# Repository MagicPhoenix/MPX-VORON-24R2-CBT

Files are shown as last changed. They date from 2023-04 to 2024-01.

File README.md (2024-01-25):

# Print Guide

## Electronics_Bay

Completely skip official `electronics_bay` folder.

Print our printed parts name started with `Elec`

You totally need these:

2pcs `Elec_Din_Clip_x2.stl`

4pcs `Elec_LRS_200_Mount_x4.STL`

1pcs `Elec_M8P_Mount.STL`

## Exhaust Filter

We use nevermore in out kit, so you can completely skip official `exhaust filter` folder.

Print these parts to seal the back panel:

1pcs `Exhaust_cover.stl`

1pcs `Exhaust_filter_grill.stl`

> This mod comes from Fictio's [Exhaust_cover](Fiction/https://github.com/VoronDesign/VoronUsers/tree/master/printer_mods/Fiction/Exhaust_cover)

## Gantry

Skip these parts:

`STLs/Gantry/AB_Drive_Units/[a]_cable_cover.stl`

`STLs/Gantry/X_Axis/XY_Joints/[a]_endstop_pod_D2F_switch.stl`

`STLs/Gantry/X_Axis/XY_Joints/[a]_endstop_pod_hall_effect.stl`

`STLs/Gantry/X_Axis/XY_Joints/[a]_endstop_pod_hall_effect.stl`

`STLs/Gantry/X_Axis/XY_Joints/[a]_xy_joint_cable_bridge_2hole.stl`

`STLs/Gantry/X_Axis/XY_Joints/[a]_xy_joint_cable_bridge_3hole.stl`

`STLs/Gantry/X_Axis/X_Carriage/*`

`STLs/Gantry/X_Axis/Z_Joints/z_joint_upper_hall_effect.stl`

## Panel_Mounting

Use `deck_support_3mm_x8.stl` and skip the 4mm one.

### If you are using Disco Stick:

Skip `Z_belt_Cover` and use our `Panel_Z_Belt Cover`:

`Panel_Z_belt_cover_A.stl`

`Panel_Z_belt_cover_B.stl`

`Panel_Z_belt_cover_Route_A.stl`

`Panel_Z_belt_cover_Route_B.stl`

> The route Z Belt Cover comes from tanaes's [whopping_Voron_mods](https://github.com/tanaes/whopping_Voron_mods/tree/main/Z_belt_cable_cover/STL)

## Skirts

Use `power_inlet_IECGS_1.2mm.stl` and skip other `power_inlet_*`

## Z Endstop

Skip this folder, we use VORON Tap as z endstop. 

## VORON Tap

Print these parts and follow offical tap guide.

https://github.com/VoronDesign/Voron-Tap/tree/main/STLs

Print `Tap_Upper_PCB_r2.stl` and skip other `Tap_Upper_*`

## Stealthburner

Skip `X_Carriage` folder

Skip `Clockwork2/cable_door.stl` and print `cable_door_for_pcb.stl`

Skip `Clockwork2/chain_*`

Print these from our github:

Print `Toolhead_Cable_Bridge.STL`

Print `Toolhead_Can_Cable_Fix.stl`

## Disco Strick 

Print 2pcs `LED_2020_x2.stl`

> This mod comes from [Daylight](https://github.com/VoronDesign/Voron-Hardware/tree/master/Daylight/Disco_on_a_stick_XXL)

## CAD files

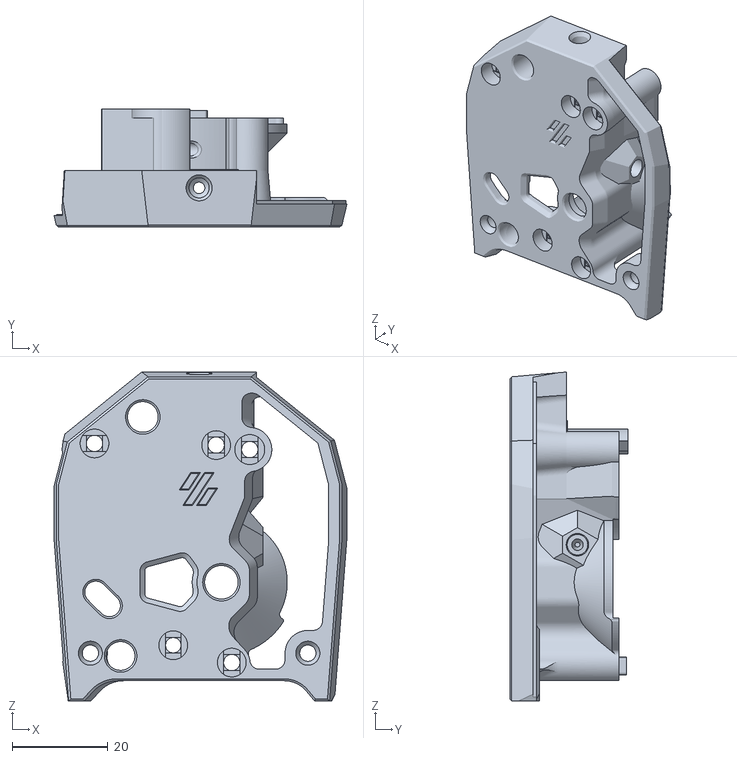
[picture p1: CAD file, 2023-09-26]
Printed Parts/Toolhead_cw2_main_body_ebbsb.stl
61.2 x 24.7 x 68.7

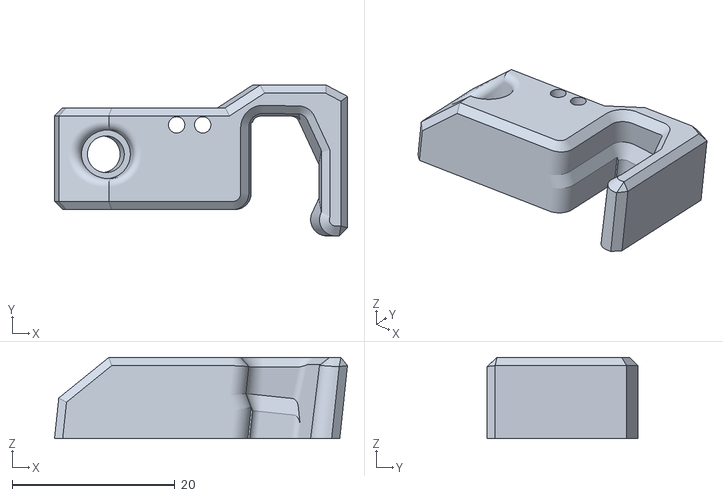
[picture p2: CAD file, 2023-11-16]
Printed Parts/Toolhead_Can_Cable_Fix.stl
36.0 x 18.5 x 9.95

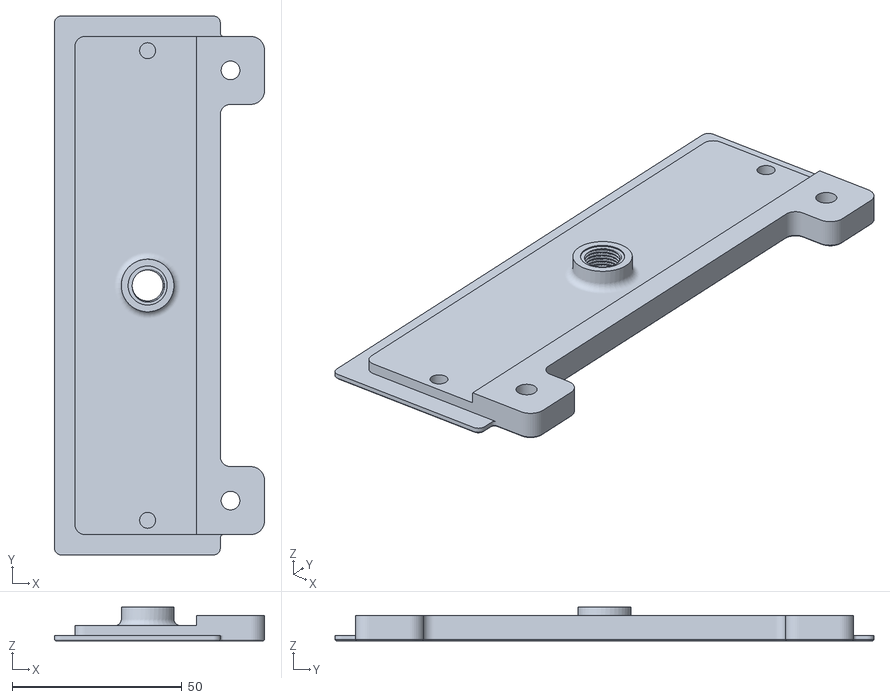
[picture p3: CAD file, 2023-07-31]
Printed Parts/Exhaust_cover.stl
61.8 x 158.6 x 10.00

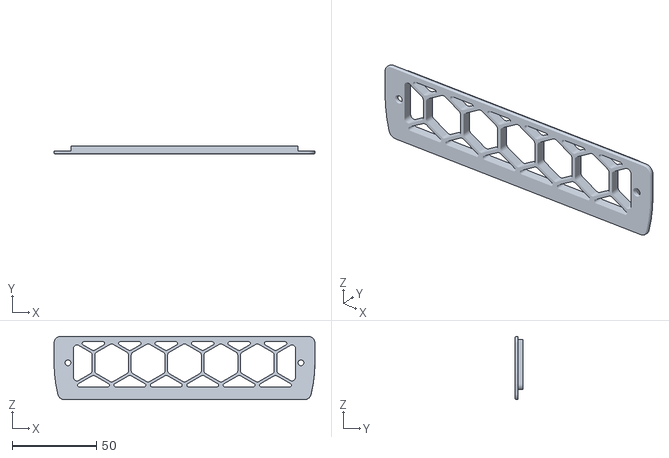
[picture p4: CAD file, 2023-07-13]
Printed Parts/Exhaust_grill.stl
154.8 x 4.60 x 37.6

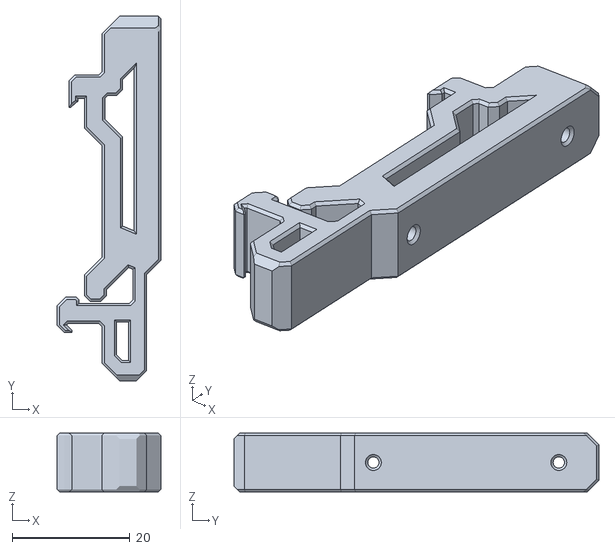
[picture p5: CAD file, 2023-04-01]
Printed Parts/Elec_Din_Clip_x2.stl
17.6 x 62.0 x 10.0

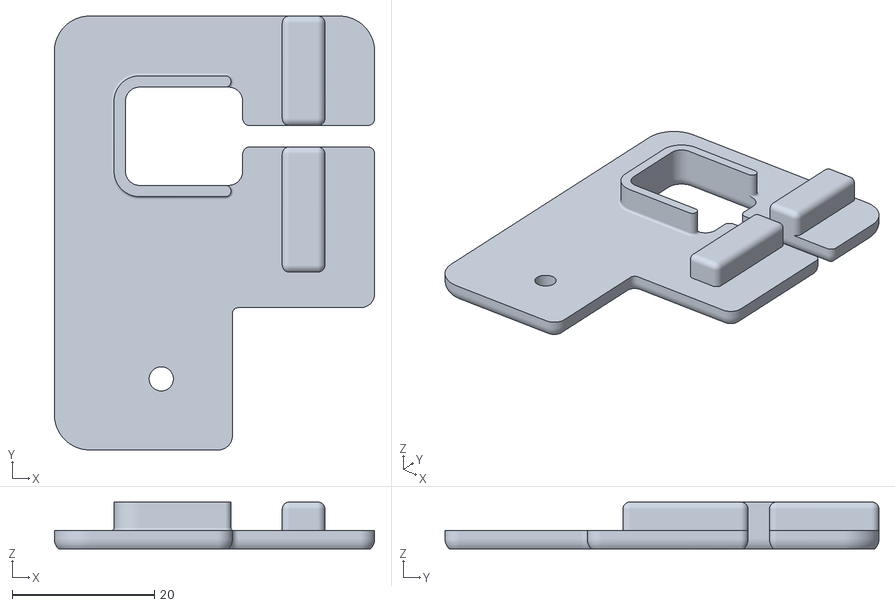
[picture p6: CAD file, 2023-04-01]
Printed Parts/Panel_Z_belt_cover_A.stl
45.0 x 61.0 x 6.60

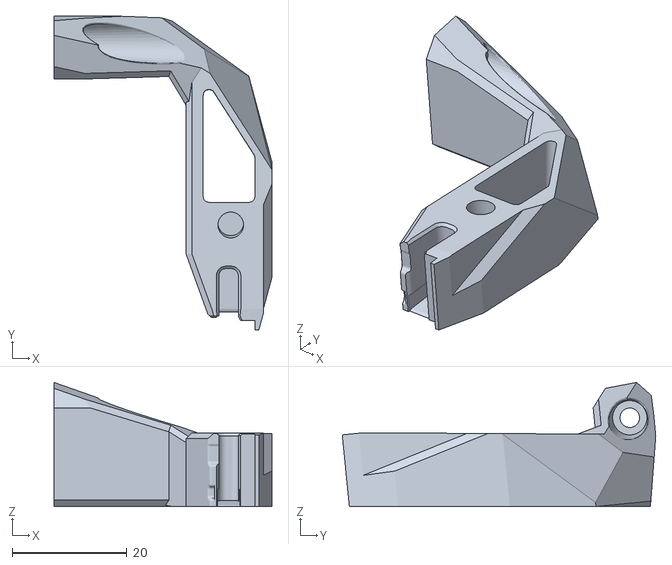
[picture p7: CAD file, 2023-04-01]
Printed Parts/Toolhead_Cable_Bridge.STL
38.0 x 54.7 x 21.7

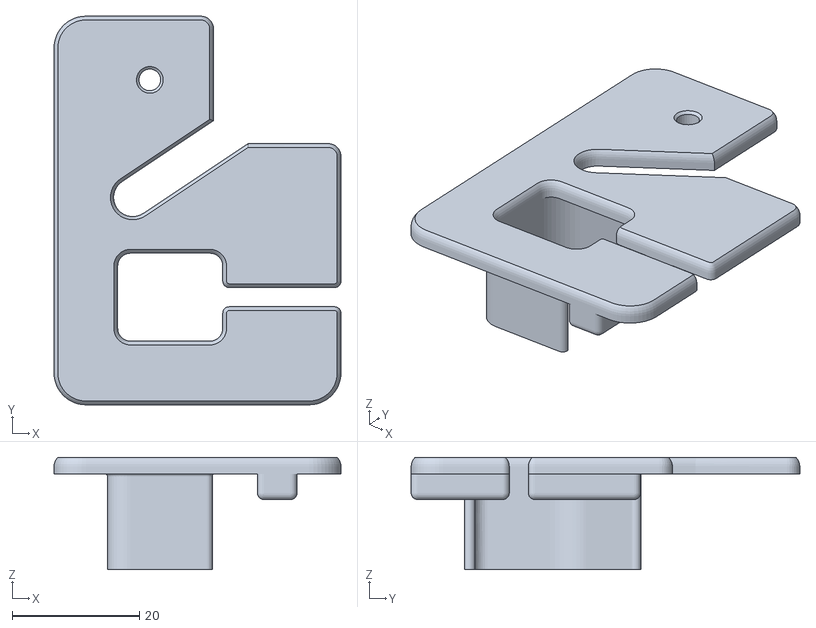
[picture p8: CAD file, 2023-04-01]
Printed Parts/Panel_Z_belt_cover_Route_A.stl
45.0 x 61.0 x 17.6

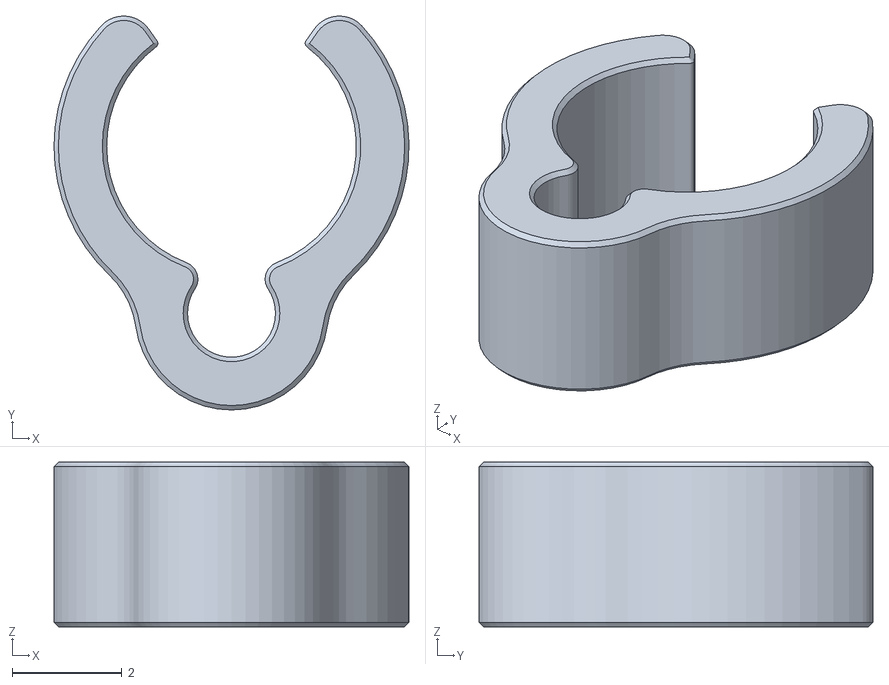
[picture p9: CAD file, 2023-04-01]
Printed Parts/Toolhead_[Optinal]Cable_Clip.STL
6.46 x 7.17 x 3.00

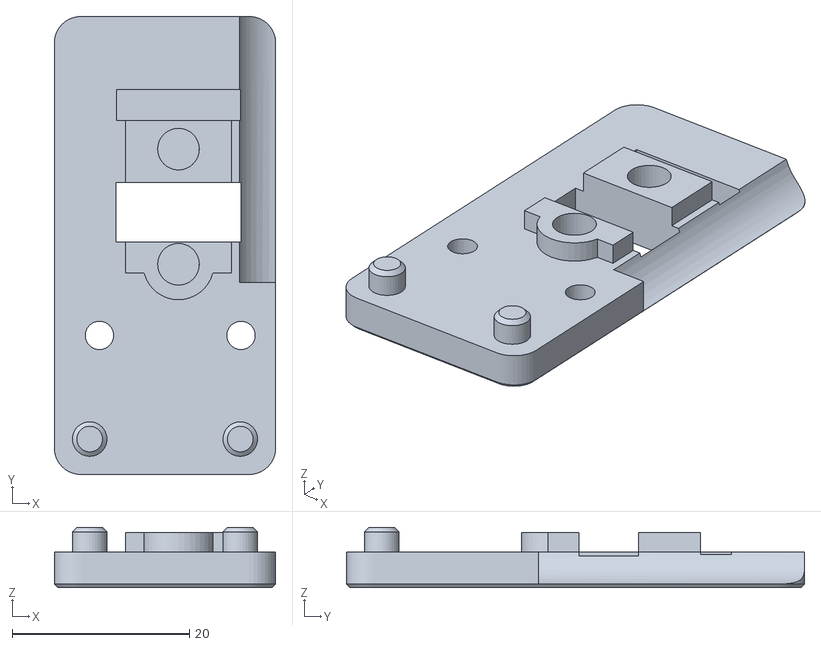
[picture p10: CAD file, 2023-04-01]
Printed Parts/Y_endstop_[a]_B.STL
25.0 x 51.7 x 6.80

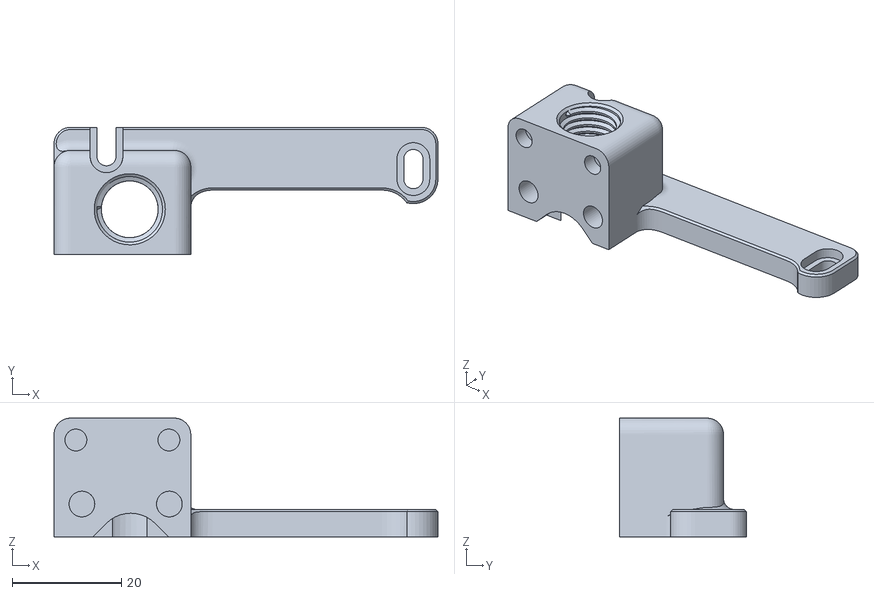
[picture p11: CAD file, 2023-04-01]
Printed Parts/Y_endstop_A.STL
70.2 x 23.3 x 21.7

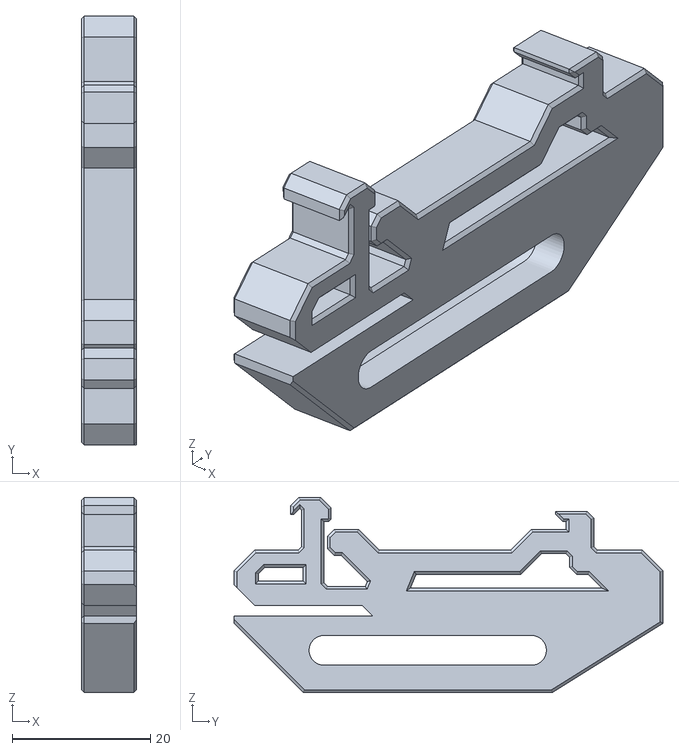
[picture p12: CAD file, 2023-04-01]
Printed Parts/Elec_LRS_200_Mount_x4.STL
8.00 x 62.0 x 28.2

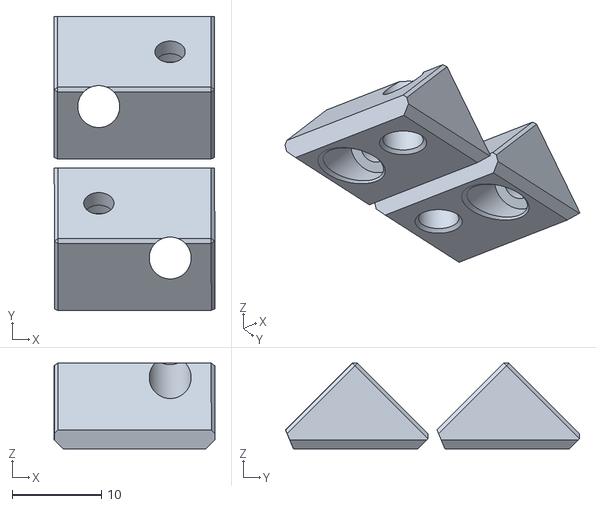
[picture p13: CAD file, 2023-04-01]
Printed Parts/LED_2020_x2.stl
18.0 x 33.0 x 9.62

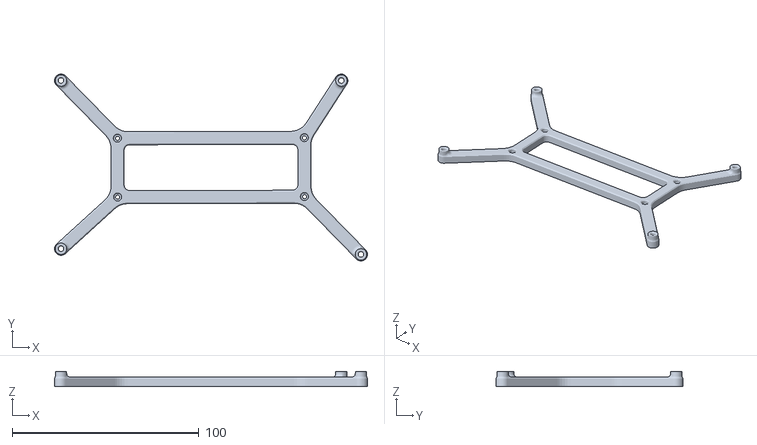
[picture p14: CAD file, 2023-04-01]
Printed Parts/Elec_M8P_Mount.STL
167.5 x 100.0 x 8.00

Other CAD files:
Printed Parts/Panel_Z_belt_cover_Route_B.stl
Printed Parts/Panel_Z_belt_cover_B.stl

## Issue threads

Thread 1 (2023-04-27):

Mirror two LRS 200 Mount parts

AdronTech, 2023-04-27:
Instead of printing the mount 4x, you have to print it 2x like it is provided and 2x mirrored.
Else the LRS is not mountable (at least in my case, as the mount is non symetrical)

Parts in question:
[Elec_LRS_200_Mount_x4.STL](https://github.com/MagicPhoenix/MPX-VORON-24R2-CBT/blob/main/Printed%20Parts/Elec_LRS_200_Mount_x4.STL)

Livezxy, 2023-04-30:
You just need to flip the mount part, they are designed to use the same part,  there'a a section in our wiki: https://mpx.wiki/assembly-tips-tricks#lrs-200-24

Closed 2023-05-05.

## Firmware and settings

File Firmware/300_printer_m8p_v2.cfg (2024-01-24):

[include mainsail.cfg]
[include stealthburner_leds.cfg]


#####################################################################
#   UUID Setting
#####################################################################
[mcu]
canbus_uuid:4b94c57be78e #YOURS WILL BE DIFFERENT - CHANGE IT  TO MATCH

[mcu EBBCan]
canbus_uuid: 2f0b1ce14660 #YOURS WILL BE DIFFERENT - CHANGE IT  TO MATCH

[printer]
kinematics: corexy
max_velocity: 300  
max_accel: 8000    			
max_z_velocity: 25 			
max_z_accel: 350
square_corner_velocity: 5.0



#####################################################################
# 	X/Y Stepper Settings
#####################################################################

## X Stepper on Motor1(B Motor rear left)
[stepper_x]
step_pin: PE6
dir_pin: PE5
enable_pin: !PC14
microsteps: 64
rotation_distance: 40
endstop_pin: ^EBBCan: PB6
position_min: 0
position_endstop: 300
position_max: 300

##--------------------------------------------------------------------
homing_speed: 100   #Max 100
homing_retract_dist: 5
homing_positive_dir: true

[tmc2209 stepper_x]
uart_pin: PC13
interpolate: False
run_current: 1.2
sense_resistor: 0.110
stealthchop_threshold: 0



## Y Stepper on Motor2 (A Motor rear right)
[stepper_y]
step_pin: PE2
dir_pin: PE1
enable_pin: !PE4
microsteps: 64

rotation_distance: 40

endstop_pin: ^PF3
position_min: 0
position_endstop: 300
position_max: 300

##--------------------------------------------------------------------
homing_speed: 100	#MAX 100
homing_retract_dist: 5
homing_positive_dir: true

[tmc2209 stepper_y]
uart_pin: PE3
interpolate: False
run_current: 1.2
sense_resistor: 0.110
stealthchop_threshold: 0


#####################################################################
# 	Z Stepper Settings
#####################################################################

## Z0 Stepper - Front Left on MOTOR3
[stepper_z]
step_pin: PB8
dir_pin: !PB7
enable_pin: !PE0
microsteps: 16
rotation_distance: 40
gear_ratio: 80:16
#endstop_pin: ^PF2
#endstop_pin: ^PF5 
endstop_pin: probe:z_virtual_endstop
position_max: 290

##--------------------------------------------------------------------
position_min: -5
homing_speed: 8
second_homing_speed: 3
homing_retract_dist: 3

[tmc2209 stepper_z]
uart_pin: PB9
interpolate: True
run_current: 1.0
sense_resistor: 0.110
stealthchop_threshold: 0



#[stepper_]##	Z1 Stepper - Rear Left on Motor4
[stepper_z1]
step_pin: PB4
dir_pin: PB3
enable_pin: !PB6
#endstop_pin: ^PF1
rotation_distance: 40
gear_ratio: 80:16
microsteps: 16

[tmc2209 stepper_z1]
uart_pin: PB5
interpolate: True
run_current: 1.0
sense_resistor: 0.110
stealthchop_threshold: 0

##	Z2 Stepper - Rear Right on Motor5
[stepper_z2]
step_pin: PG13
dir_pin: PG12
enable_pin: !PG15
rotation_distance: 40
gear_ratio: 80:16
microsteps: 16

[tmc2209 stepper_z2]
uart_pin: PG14
interpolate: True
run_current: 1.0
sense_resistor: 0.110
stealthchop_threshold: 0

##	Z3 Stepper - Front Right on Motor6
[stepper_z3]
step_pin: PG9
dir_pin: PD7
enable_pin: !PG11
rotation_distance: 40
gear_ratio: 80:16
microsteps: 16

[tmc2209 stepper_z3]
uart_pin: PG10
interpolate: True
run_current: 1.0
sense_resistor: 0.110
stealthchop_threshold: 0

[extruder]
step_pin: EBBCan: PD0
dir_pin: EBBCan: PD1
enable_pin: !EBBCan: PD2
microsteps: 16
rotation_distance: 22.6789511 # WEstys 21.928277 
gear_ratio: 50:10
nozzle_diameter: 0.400
filament_diameter: 1.750
heater_pin: EBBCan: PB13
sensor_type: Generic 3950 ##COMMENT OUT THIS LINE AND sensor_pin line below IF YOU HAVE RAPIDO V2
sensor_pin: EBBCan: PA3
pressure_advance: 0.036
control: pid
pid_Kp: 21.527
pid_Ki: 1.063
pid_Kd: 108.982
min_temp: 0
max_temp: 300
min_extrude_temp: 0                                   ## use this for estep calbration only##
#min_extrude_temp: 230                                ## enable this ones you have done extruder calibration steps and comment out the above line.
#max_extrude_cross_section: 5# KAMP setting needed

# NTC100K B3950
sensor_type: Generic 3950 #ATC Semitec 104NT-4-R025H42G
sensor_pin: EBBCan: PA3 #if you renamed your board make sure to match the board assignment in front of the pin

###########################
#ENABLE BELOW 7 lINES IF YOU HAVE V2 RAPIDO#
###########################

# PT100 / PT1000
# sensor_type: MAX31865
# sensor_pin: EBBCan: PA4
# spi_bus: spi1
# rtd_nominal_r: 100
# rtd_reference_r: 430
# rtd_num_of_wires: 2


[tmc2209 extruder]
uart_pin: EBBCan: PA15
run_current: 0.3
stealthchop_threshold: 999999


[fan]
pin: EBBCan: PA1
kick_start_time: 0.5
off_below: 0.5

[heater_fan hotend_fan]
pin: EBBCan: PA0
max_power: 1.0
kick_start_time: 0.5
heater: extruder
heater_temp: 50.0
##  If you are experiencing back flow, you can reduce fan_speed
#fan_speed: 1.0




[heater_bed]
heater_pin: PA1
sensor_type: Generic 3950
sensor_pin: PB1
max_power: 1.0
min_temp: 0
max_temp: 120
control: pid
pid_kp: 58.437
pid_ki: 2.347
pid_kd: 363.769

[temperature_sensor buildplate]
sensor_type: Generic 3950
sensor_pin: PB0
min_temp: -40
max_temp: 120

[temperature_sensor chamber]
sensor_type: Generic 3950
sensor_pin: PC5
min_temp: -40
max_temp: 120


[temperature_sensor EBB_NTC]
sensor_type: Generic 3950
sensor_pin: EBBCan: PA2
min_temp: -40
max_temp: 100

[temperature_sensor CB1]
sensor_type: temperature_host



[probe]
pin: ^EBBCan: PB5
z_offset: 0
speed: 10.0
samples: 3
samples_result: median
sample_retract_dist: 3.0
samples_tolerance: 0.006
samples_tolerance_retries: 3

##################################################################
#             TAP MACRO TO CHECK OVER 150DEGREES                  #
##################################################################

## THE BELOW CODE STOPS THE TAP HOMING INTO THE BED AT PROBE TEMPS OVER 150°C##
activate_gcode:
    {% set PROBE_TEMP = 150 %}
    {% set MAX_TEMP = PROBE_TEMP + 5 %}
    {% set ACTUAL_TEMP = printer.extruder.temperature %}
    {% set TARGET_TEMP = printer.extruder.target %}

    {% if TARGET_TEMP > PROBE_TEMP %}
        { action_respond_info('Extruder temperature target of %.1fC is too high, lowering to %.1fC' % (TARGET_TEMP, PROBE_TEMP)) }
        M109 S{ PROBE_TEMP }
    {% else %}
        # Temperature target is already low enough, but nozzle may still be too hot.
        {% if ACTUAL_TEMP > MAX_TEMP %}
            { action_respond_info('Extruder temperature %.1fC is still too high, waiting until below %.1fC' % (ACTUAL_TEMP, MAX_TEMP)) }
            TEMPERATURE_WAIT SENSOR=extruder MAXIMUM={ MAX_TEMP }
        {% endif %}
    {% endif %}



[multi_pin controller_fans]
pins: PF7,PF9

[controller_fan controller_fan]
##  Controller fan
pin: multi_pin:controller_fans
max_power: 0.4
kick_start_time: 0.5
heater: heater_bed



[heater_fan nevermore_fan]
#  Exhaust fan - Nevermore Filter
pin: PF8 #3rd from left below voltage jumpers
max_power: 1.0
shutdown_speed: 0.0
kick_start_time: 5.0
heater: heater_bed
heater_temp: 60
fan_speed: 1.0 

[quad_gantry_level]
gantry_corners:
	-60,-10
	360,370
points:
	50,25
	50,225
	250,225
	250,25

#--------------------------------------------------------------------
speed: 300
horizontal_move_z: 10
retries: 5
retry_tolerance: 0.0075
max_adjust: 10

[bed_mesh]
speed: 300
horizontal_move_z: 5
mesh_min: 10,10
mesh_max: 290,290
probe_count: 5,5
algorithm: bicubic
bicubic_tension: 0.2

[adxl345]
cs_pin: EBBCan: PB12
spi_software_sclk_pin: EBBCan: PB10
spi_software_mosi_pin: EBBCan: PB11
spi_software_miso_pin: EBBCan: PB2
axes_map: z,-y,x

[resonance_tester]
probe_points: 150, 150, 20
accel_chip: adxl345


[display]
#	mini12864 LCD Display
lcd_type: uc1701
cs_pin: EXP1_3
a0_pin: EXP1_4
rst_pin: EXP1_5
encoder_pins: ^EXP2_5, ^EXP2_3
click_pin: ^!EXP1_2
contrast: 63
spi_software_miso_pin: EXP2_1
spi_software_mosi_pin: EXP2_6
spi_software_sclk_pin: EXP2_2

[neopixel btt_mini12864]
#	To control Neopixel RGB in mini12864 display
pin: EXP1_6
chain_count: 3
initial_RED: 0.1
initial_GREEN: 0.5
initial_BLUE: 0.0
color_order: RGB

##	Set RGB values on boot up for each Neopixel. 
##	Index 1 = display, Index 2 and 3 = Knob
[delayed_gcode setdisplayneopixel]
initial_duration: 1
gcode:
       SET_LED LED=btt_mini12864 RED=1 GREEN=1 BLUE=1 INDEX=1 TRANSMIT=0
       SET_LED LED=btt_mini12864 RED=1 GREEN=0 BLUE=0 INDEX=2 TRANSMIT=0
       SET_LED LED=btt_mini12864 RED=1 GREEN=0 BLUE=0 INDEX=3 


#################################################
################### Disco Led ###################
#################################################
[neopixel disco1]
pin: PD15
chain_count: 25
color_order: BGRW
initial_RED: 1.0
initial_GREEN: 1.0
initial_BLUE: 1.0

[neopixel disco2]
pin: PB15
chain_count: 25
color_order: BGRW
initial_RED: 1.0
initial_GREEN: 1.0
initial_BLUE: 1.0
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

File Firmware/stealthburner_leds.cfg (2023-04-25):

# Macros for setting the status leds on the Voron StealthBurner toolhead (or for any neopixel-type leds).
#
# You will need to configure a neopixel (or other addressable led, such as dotstar). See
# https://www.klipper3d.org/Config_Reference.html#neopixel for configuration details.


#####################################
#           INSTRUCTIONS            #
#####################################
# How to use all this stuff:
#
#     1.  Copy this .cfg file into your Klipper config directory and then add [include stealthburner_leds.cfg]
#         to the top of your printer.cfg in order to register the LEDs and macros with Klipper.
#     2.  Define your LEDs by editing [neopixel sb_leds] below and entering the data pin from your control board
#         as well as the color order.
#
#           Note: RGB and RGBW are different and must be defined explicitly.  RGB and RGBW are also not able to 
#                 be mix-and-matched in the same chain. A separate data line would be needed for proper functioning.
#
#                 RGBW LEDs will have a visible yellow-ish phosphor section to the chip.  If your LEDs do not have
#                 this yellow portion, you have RGB LEDs.
#
#     3.  Save your config and restart Klipper.
#
#           Note: We set RED and BLUE to 1.0 to make it easier for users and supporters to detect 
#                 misconfigurations or miswiring. The default color format is for Neopixels with a dedicated 
#                 white LED. On startup, all three SB LEDs should light up.
#
#                 If you get random colors across your LEDs, change the color_order to GRB and restart. Then
#                 omit the W for each suggested color_order in the next paragraph.
#
#                 If you get MAGENTA, your  color order is correct. If you get CYAN, you need to use RGBW. If
#                 you get YELLOW, you need to use BRGW (note that BRG is only supported in the latest Klipper
#                 version).
#
#     4.  Once you have confirmed that the LEDs are set up correctly, you must now decide where you want 
#         these macros called up...which means adding them to your existing gcode macros.  NOTHING will happen
#         unless you add the STATUS_????? macros to your existing gcode macros.  
#
#           Example: add STATUS_LEVELING to the beginning of your QGL gcode macro, and then add STATUS_READY 
#                    to the end of it to set the logo LED and nozzle LEDs back to the `ready` state.
#
#           Example: add STATUS_CLEANING to the beginning of your nozzle-cleaning macro, and then STATUS_READY
#                    to the end of it to return the LEDs back to `ready` state.
#
#     5.  Feel free to change colors of each macro, create new ones if you have a need to.  The macros provided below
#         are just an example of what is possible.  If you want to try some more complex animations, you will most
#         likely have to use WLED with Moonraker and a small micro-controller 
#
#####################################
#       END INSTRUCTRUCTIONS        #
#####################################







[neopixel sb_leds]
pin: EBBCan:PD3
#   The pin connected to the neopixel. This parameter must be provided.
chain_count: 3
#   The number of Neopixel chips that are "daisy chained" to the
#   provided pin. The default is 1 (which indicates only a single
#   Neopixel is connected to the pin).
color_order: GRBW
#   Set the pixel order required by the LED hardware. Options are GRB,
#   RGB, GRBW, or RGBW. The default is GRB.
initial_RED: 1.0
initial_GREEN: 0.0
initial_BLUE: 0.0
initial_WHITE: 0.0
#   Sets the initial LED color of the Neopixel. Each value should be
#   between 0.0 and 1.0. The WHITE option is only available on RGBW
#   LEDs. The default for each color is 0.#

# Most configuration for the macros can be done by modifying the variables in the _sb_vars macro
# at the start of this file.

##########
# MACROS #
##########

# The following status macros are available (these go inside of your macros):
#
#    STATUS_READY
#    STATUS_OFF
#    STATUS_BUSY
#    STATUS_HEATING
#    STATUS_LEVELING
#    STATUS_HOMING
#    STATUS_CLEANING
#    STATUS_MESHING
#    STATUS_CALIBRATING_Z
#
# With additional macros for basic control:
#
#    SET_NOZZLE_LEDS_ON
#    SET_LOGO_LEDS_OFF
#    SET_NOZZLE_LEDS_OFF
#
# Contributed by Voron discord users wile.e, Tetsunosuke, and etherwalker


[gcode_macro _sb_vars]
# User settings for the StealthBurner status leds. You can change the status colors and led
# configurations for the logo and nozzle here.
variable_colors: {
        'logo': { # Colors for logo states
            'busy': {'r': 0.4, 'g': 0.0, 'b': 0.0, 'w': 0.0},
            'cleaning': {'r': 0.0, 'g': 0.02, 'b': 0.5, 'w': 0.0},
            'calibrating_z': {'r': 0.8, 'g': 0., 'b': 0.35, 'w': 0.0},
            'heating': {'r': 0.3, 'g': 0.18, 'b': 0.0, 'w': 0.0},
            'homing': {'r': 0.0, 'g': 0.6, 'b': 0.2, 'w': 0.0},
            'leveling': {'r': 0.5, 'g': 0.1, 'b': 0.4, 'w': 0.0},
            'meshing': {'r': 0.2, 'g': 1.0, 'b': 0.0, 'w': 0.0},
            'off': {'r': 0.0, 'g': 0.0, 'b': 0.0, 'w': 0.0},
            'printing': {'r': 1.0, 'g': 0.0, 'b': 0.0, 'w': 0.0},
            'standby': {'r': 0.01, 'g': 0.01, 'b': 0.01, 'w': 0.1},
        },
        'nozzle': { # Colors for nozzle states
            'heating': {'r': 0.8, 'g': 0.35, 'b': 0.0, 'w':0.0},
            'off': {'r': 0.0, 'g': 0.0, 'b': 0.0, 'w': 0.0},
            'on': {'r': 0.8, 'g': 0.8, 'b': 0.8, 'w':1.0},
            'standby': {'r': 0.6, 'g': 0.0, 'b': 0.0, 'w':0.0},
        },
        'thermal': {
            'hot': {'r': 1.0, 'g': 0.0, 'b': 0.0, 'w': 0.0},
            'cold': {'r': 0.3, 'g': 0.0, 'b': 0.3, 'w': 0.0}
        }
    }
variable_logo_led_name:         "sb_leds" 
# The name of the addressable LED chain that contains the logo LED(s)
variable_logo_idx:              "1" 
# A comma-separated list of indexes LEDs in the logo
variable_nozzle_led_name:       "sb_leds"
# The name of the addressable LED chain that contains the nozzle LED(s). This will
# typically be the same LED chain as the logo.
variable_nozzle_idx:            "2,3"
# A comma-separated list of indexes of LEDs in the nozzle
gcode:
    # This section is required.  Do Not Delete.


[gcode_macro _set_sb_leds]
gcode:
    {% set red = params.RED|default(0)|float %}
    {% set green = params.GREEN|default(0)|float %}
    {% set blue = params.BLUE|default(0)|float %}
    {% set white = params.WHITE|default(0)|float %}
    {% set led = params.LED|string %}
    {% set idx = (params.IDX|string).split(',') %}
    {% set transmit_last = params.TRANSMIT|default(1) %}

    {% for led_index in idx %}
        {% set transmit=transmit_last if loop.last else 0 %}
        set_led led={led} red={red} green={green} blue={blue} white={white} index={led_index} transmit={transmit}
    {% endfor %}

[gcode_macro _set_sb_leds_by_name]
gcode:
    {% set leds_name = params.LEDS %}
    {% set color_name = params.COLOR %}
    {% set color = printer["gcode_macro _sb_vars"].colors[leds_name][color_name] %}
    {% set led = printer["gcode_macro _sb_vars"][leds_name + "_led_name"] %}
    {% set idx = printer["gcode_macro _sb_vars"][leds_name + "_idx"] %}
    {% set transmit = params.TRANSMIT|default(1) %}

    _set_sb_leds led={led} red={color.r} green={color.g} blue={color.b} white={color.w} idx="{idx}" transmit={transmit}

[gcode_macro _set_logo_leds]
gcode:
    {% set red = params.RED|default(0)|float %}
    {% set green = params.GREEN|default(0)|float %}
    {% set blue = params.BLUE|default(0)|float %}
    {% set white = params.WHITE|default(0)|float %}
    {% set led = printer["gcode_macro _sb_vars"].logo_led_name %}
    {% set idx = printer["gcode_macro _sb_vars"].logo_idx %}
    {% set transmit=params.TRANSMIT|default(1) %}

    _set_sb_leds led={led} red={red} green={green} blue={blue} white={white} idx="{idx}" transmit={transmit}

[gcode_macro _set_nozzle_leds]
gcode:
    {% set red = params.RED|default(0)|float %}
    {% set green = params.GREEN|default(0)|float %}
    {% set blue = params.BLUE|default(0)|float %}
    {% set white = params.WHITE|default(0)|float %}
    {% set led = printer["gcode_macro _sb_vars"].nozzle_led_name %}
    {% set idx = printer["gcode_macro _sb_vars"].nozzle_idx %}
    {% set transmit=params.TRANSMIT|default(1) %}

    _set_sb_leds led={led} red={red} green={green} blue={blue} white={white} idx="{idx}" transmit={transmit}

[gcode_macro set_logo_leds_off]
gcode:
    {% set transmit=params.TRANSMIT|default(1) %}
    _set_logo_leds red=0 blue=0 green=0 white=0 transmit={transmit}

[gcode_macro set_nozzle_leds_on]
gcode:
    {% set transmit=params.TRANSMIT|default(1) %}
    _set_sb_leds_by_name leds="nozzle" color="on" transmit={transmit}

[gcode_macro set_nozzle_leds_off]
gcode:
    {% set transmit=params.TRANSMIT|default(1) %}
    _set_sb_leds_by_name leds="nozzle" color="off" transmit={transmit}
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

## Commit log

2023-04-07 Delete Exhaust_filter_grill.stl
    remove useless part
    [Exhaust_filter_grill.stl]
2023-04-07 Create printer.cfg
    add 350mm firmware
    [printer.cfg]
2023-04-10 update exhaust
    [Exhaust_cover.stl, Exhaust_grill.stl]
2023-04-25 update firmware
    [300_printer.cfg, 350_printer.cfg, stealthburner_leds.cfg]
2023-05-18 uncomment probe offset and pid
    [300_printer.cfg, 350_printer.cfg, printer.cfg]
2023-06-05 update arc setting to avoid timer too close issue
    [300_printer.cfg, 350_printer.cfg]
2023-07-01 add nevermore config
    [300_printer.cfg, 350_printer.cfg]
2023-09-18 adding sensor type for PT1000 on extruder
    [300_printer.cfg, 350_printer.cfg]
2023-09-26 update ebb body
    [Toolhead_cw2_main_body_ebbsb.stl]
2023-10-11 change firmware to M8P V2
    [300_printer_m8p_v1.cfg, 350_printer_m8p_v1.cfg, 350_printer_m8p_v2.cfg]
2023-10-12 update can cable fix stl
    [Toolhead_Can_Cable_Fix.stl]
2023-10-17 Update 350_printer_m8p_v2.cfg
    [heater_bed]
    heater_pin: PA1
    sensor_type: Generic 3950
    sensor_pin: PB1
    [350_printer_m8p_v2.cfg]
2023-11-16 change to Rudedog's fixed can cable mount
    [350_printer_m8p_v2.cfg, Toolhead_Can_Cable_Fix.stl]
2023-12-24 Update file name and add missing [ in tmc2209 stepper_y section
    [300_printer_m8p_v2.cfg, 300_printer_m8p_v2.cfg.cfg]
2023-12-30 Update 300_printer_m8p_v2.cfg
    fixed wrong uart pin
    [300_printer_m8p_v2.cfg]
2024-01-24 remove sensorless from printer.cfg
    [300_printer_m8p_v2.cfg]
